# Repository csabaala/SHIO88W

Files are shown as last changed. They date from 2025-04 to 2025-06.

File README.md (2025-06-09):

# SHIO88W

ESP32 based DIN rail mount IO board.

More [Pictures](/Pictures#assembled-boards) and [Video](https://youtu.be/fpFCvI0ayuA) of the assembled board and extensions.

Example [ESPHome configs](/ESPHome)

## Features

* 12V DC input for powering
* 8 open collector output (50 mA load per channel)
* 8 opto isolated input
* LEDs for output and input status
* 1 sensor input (ds18b20, dht)
* 14 pin IDC connector for direct GPIO access

View [3D model](https://3dviewer.net/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)

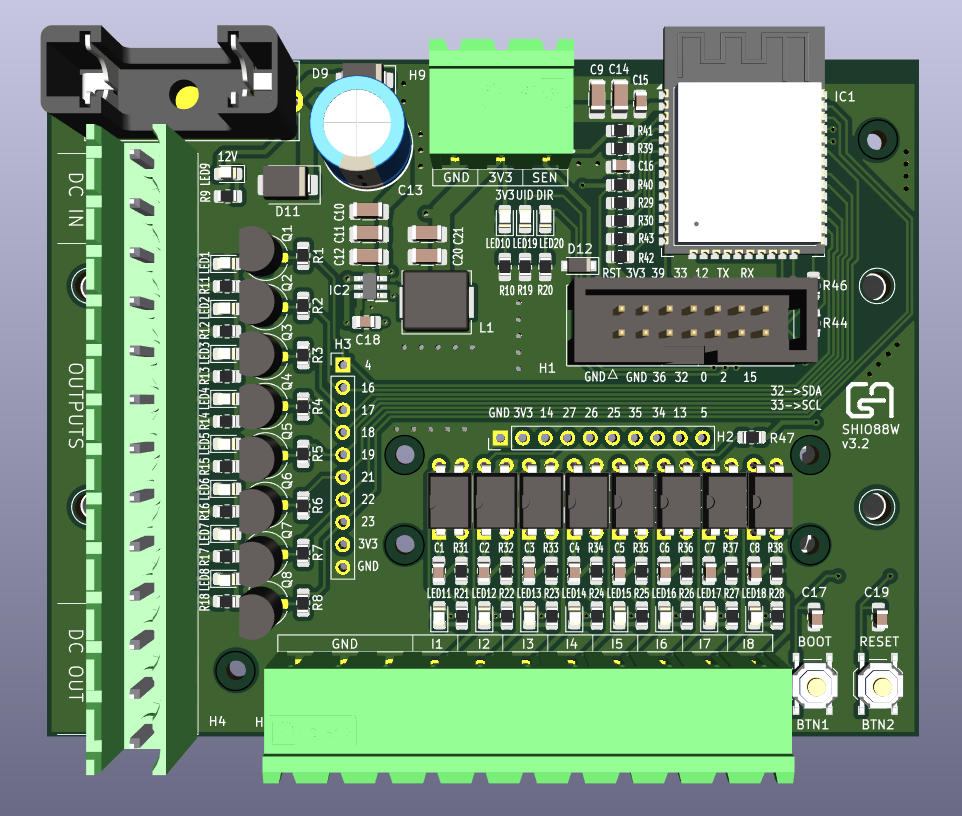
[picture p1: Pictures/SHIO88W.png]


## Extensions

### SHADRS485

Extension board mountable top of the SHIO88W board.

* Sockets and breakout for 2 ADS1115 AD converter
* On board voltage dividers for each channel
* RS-485 interface

View [3D model](https://3dviewer.net/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)

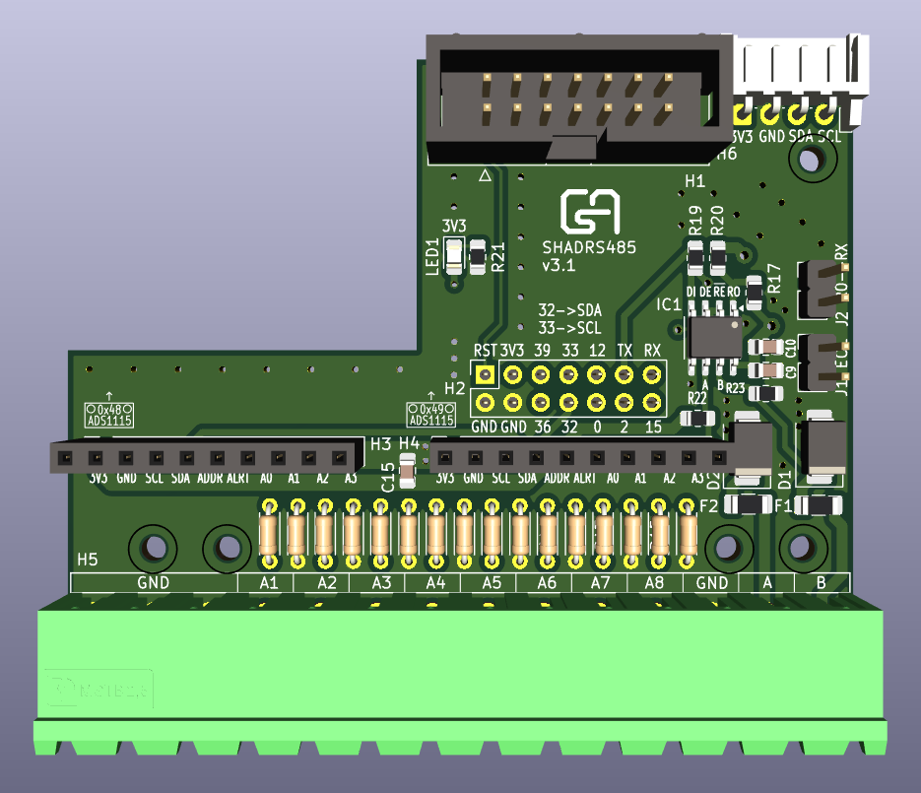
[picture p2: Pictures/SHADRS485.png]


### SHHMI

Control interface for SHIO88W.

* PCB for 128x64 OLED display and control buttons. Fits the 0.96 and 1.3 inch OLED versions.
* Mountable top of the SHADRS485 board

View [3D model](https://3dviewer.net/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)

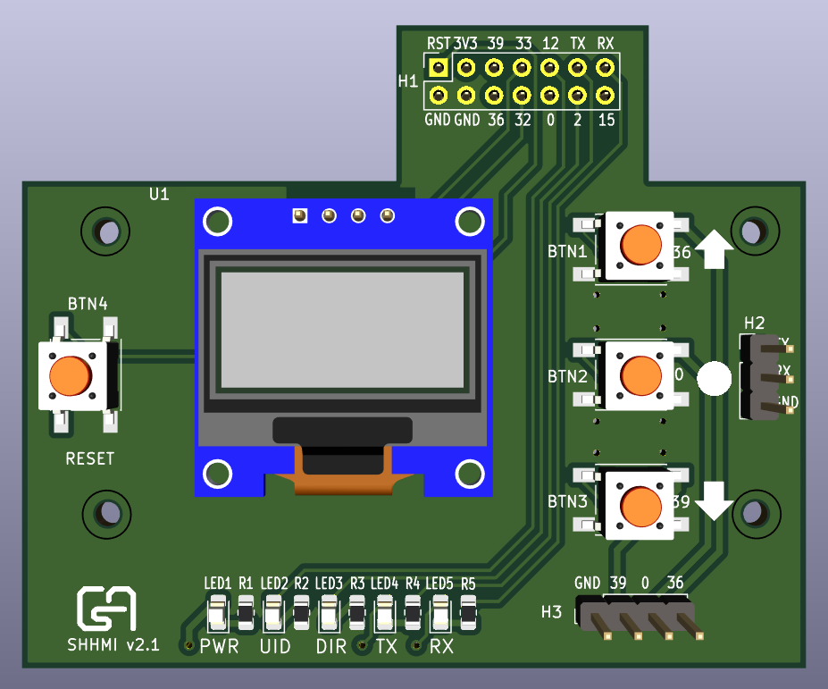
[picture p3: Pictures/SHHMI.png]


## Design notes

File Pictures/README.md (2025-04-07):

## Assembled boards

The SMD components sitting on the front side of the SHIO88W board manufactured by JLCPCB SMT assembly.

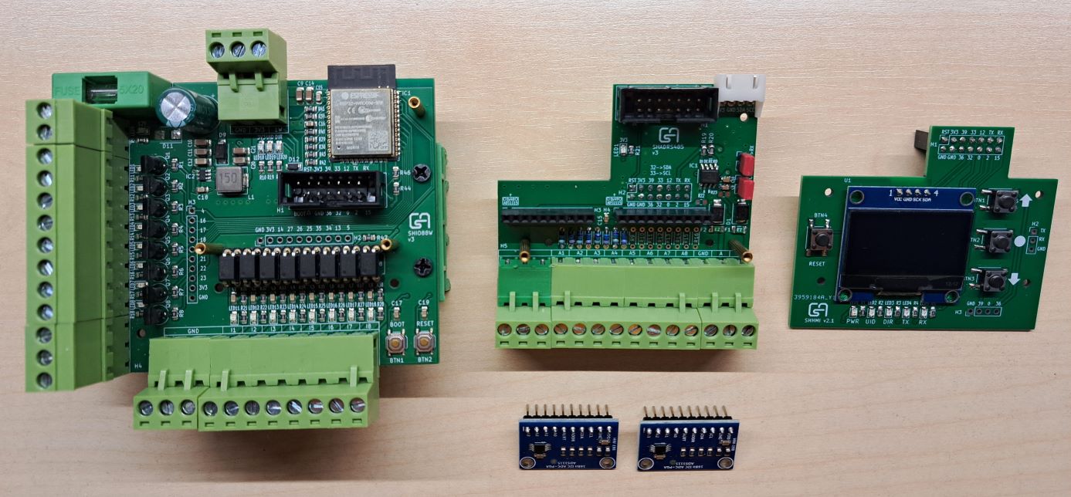
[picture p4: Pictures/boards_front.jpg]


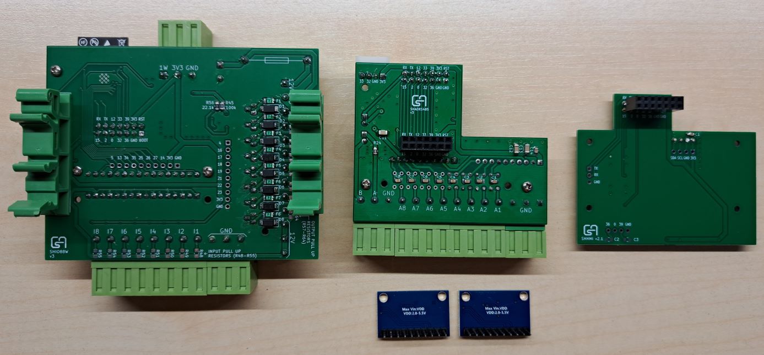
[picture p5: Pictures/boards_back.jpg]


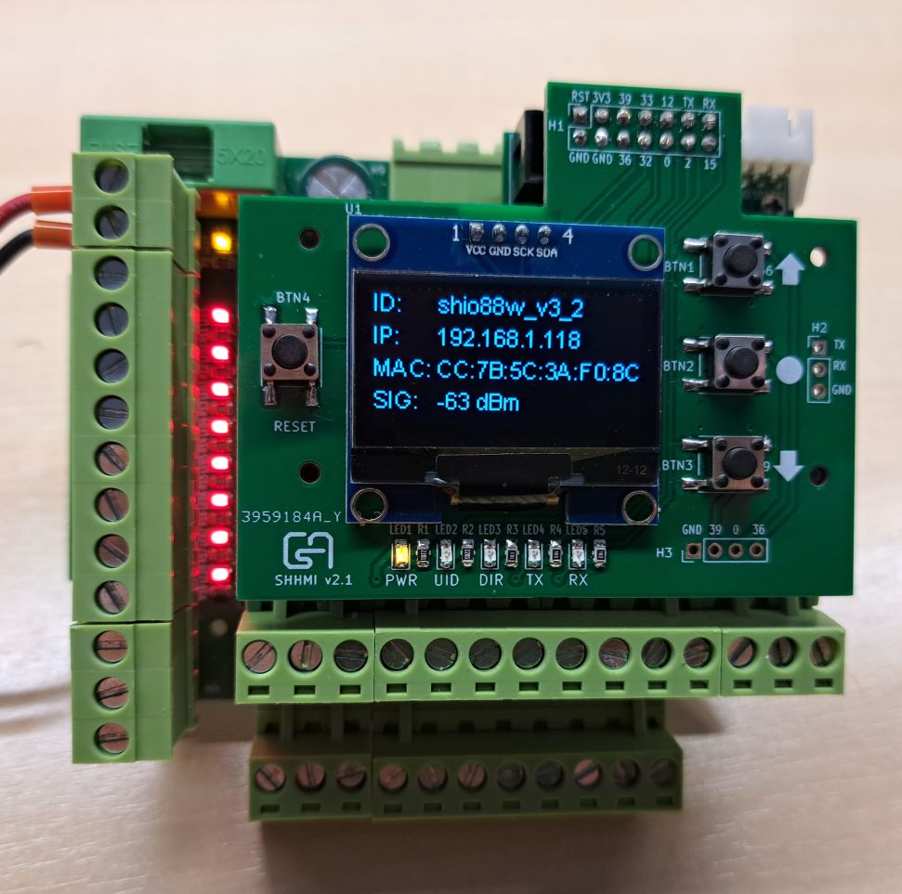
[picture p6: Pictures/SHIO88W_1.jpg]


Fits into home distribution boxes:

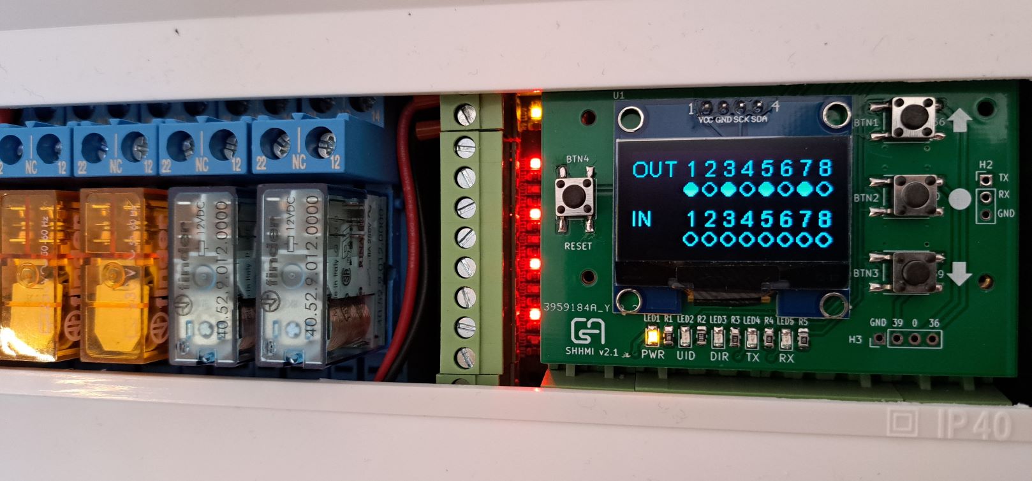
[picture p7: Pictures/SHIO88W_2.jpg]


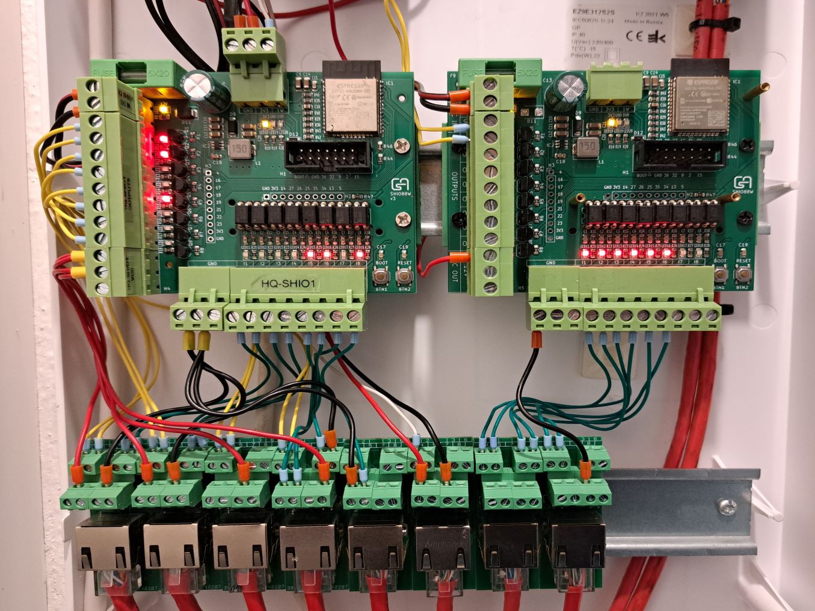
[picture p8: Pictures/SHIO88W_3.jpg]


## SHADRS485

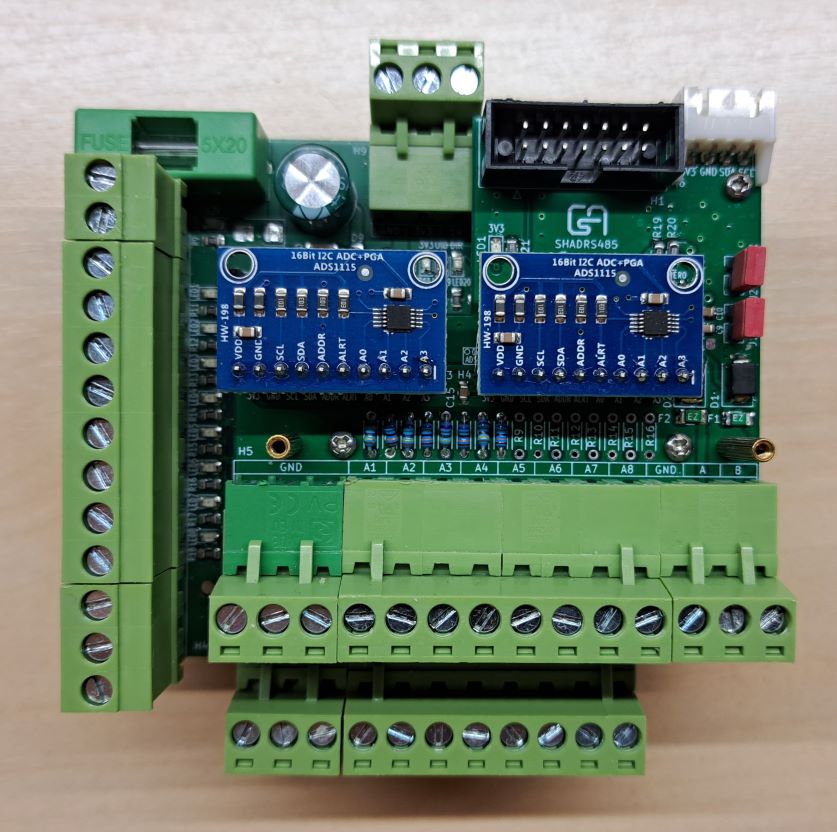
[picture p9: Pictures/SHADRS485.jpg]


## 3D images

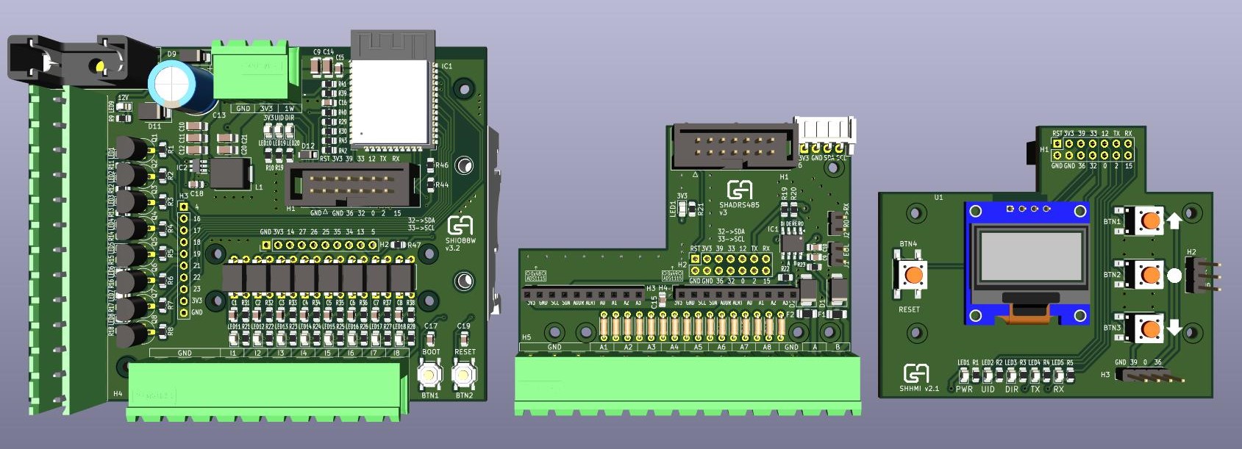
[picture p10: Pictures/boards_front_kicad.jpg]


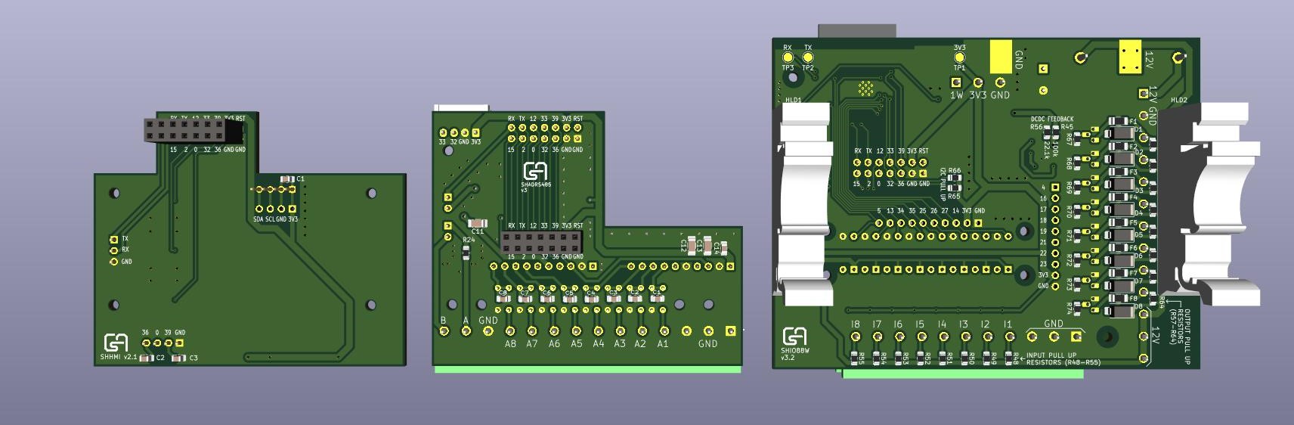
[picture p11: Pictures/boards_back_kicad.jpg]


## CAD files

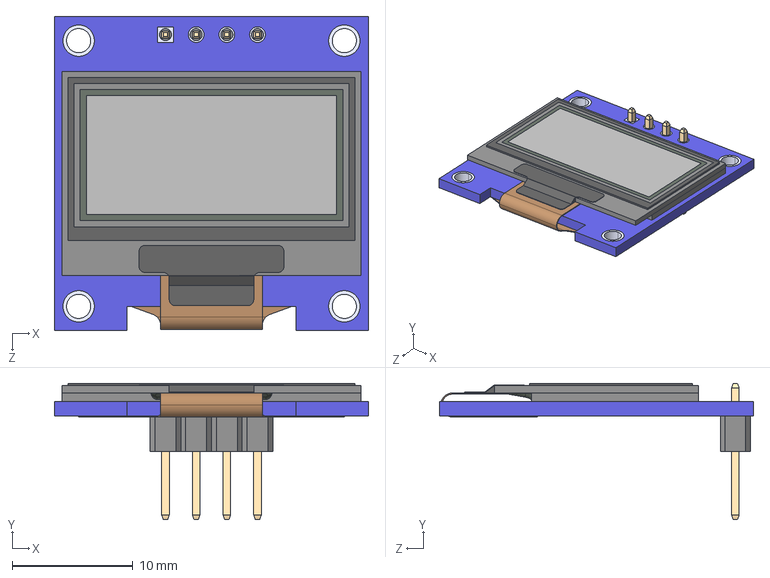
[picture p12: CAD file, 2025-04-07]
Hardware/SHHMI/extras/DM-OLED096-636.step
26.0 x 11.3 x 26.0 mm
DM-OLED096-636_Module
DM-OLED096-636_Panel

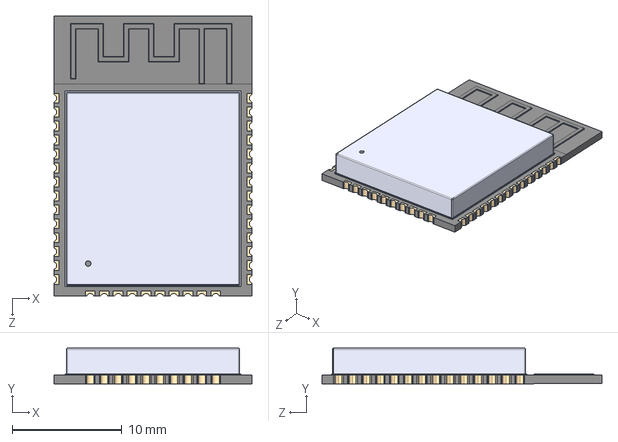
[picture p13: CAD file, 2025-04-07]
Hardware/SHIO88W/extras/ESP32-WROOM-32E.STEP
18.0 x 3.25 x 25.5 mm

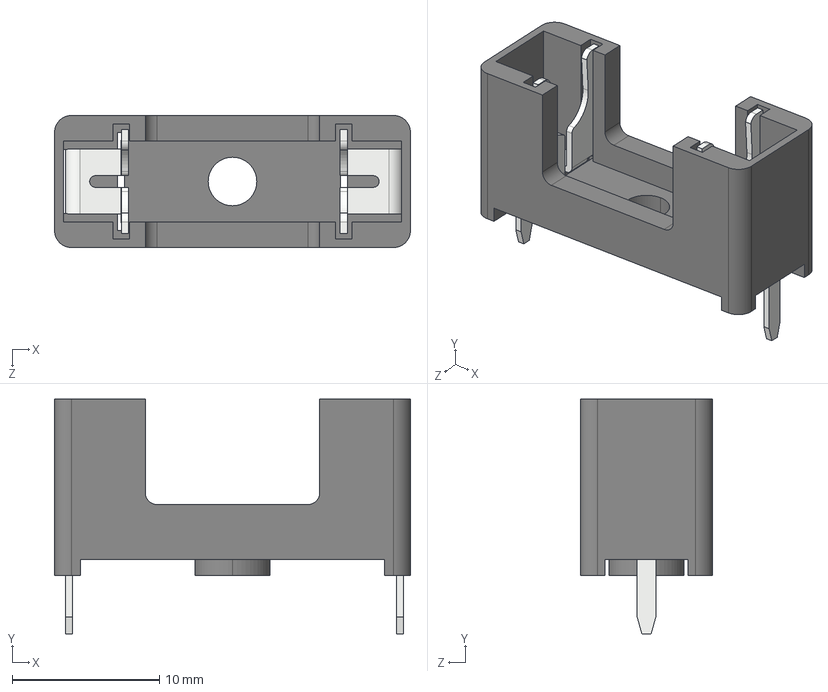
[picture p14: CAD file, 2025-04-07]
Hardware/SHIO88W/extras/fuse/4628.step
24.2 x 16.0 x 8.99 mm

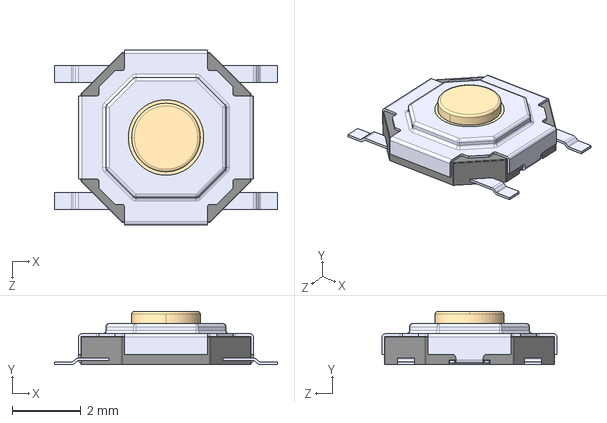
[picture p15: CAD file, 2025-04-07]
Hardware/SHIO88W/extras/TS-1187A-B-A-B.STEP
6.50 x 1.55 x 5.10 mm

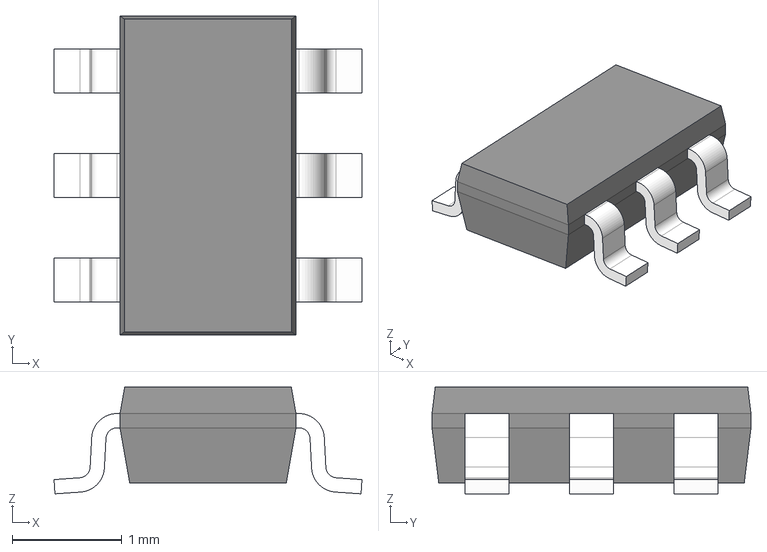
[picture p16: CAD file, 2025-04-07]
Hardware/SHIO88W/extras/LMR51420/LMR51420XDDCR.stp
2.80 x 2.90 x 0.97 mm
BODY-SOT
LEAD-SOT x 6

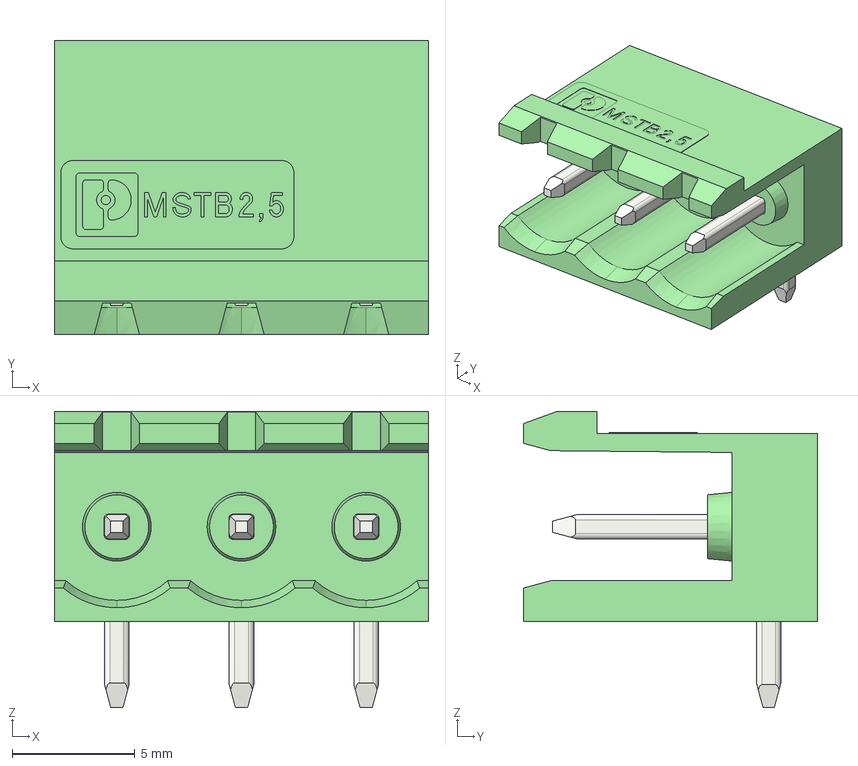
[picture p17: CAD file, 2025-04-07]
Hardware/SHIO88W/extras/MSTB 2,5 3-G-5,08/1759020.step
15.2 x 12.0 x 12.1 mm

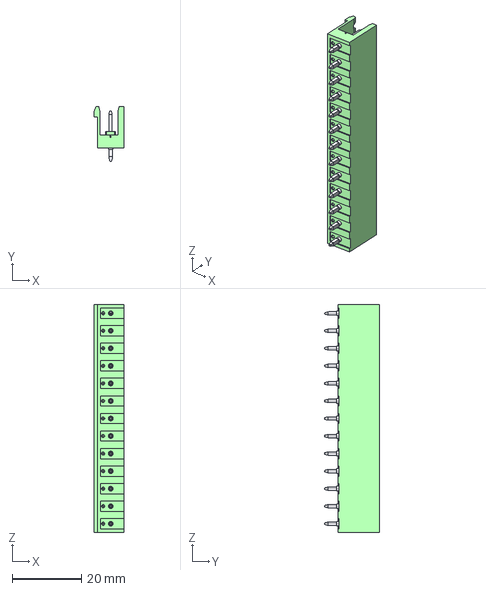
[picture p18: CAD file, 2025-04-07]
Hardware/SHIO88W/extras/MSTBV 2,513-G-5,08/1758128.stp
8.60 x 15.9 x 66.0 mm

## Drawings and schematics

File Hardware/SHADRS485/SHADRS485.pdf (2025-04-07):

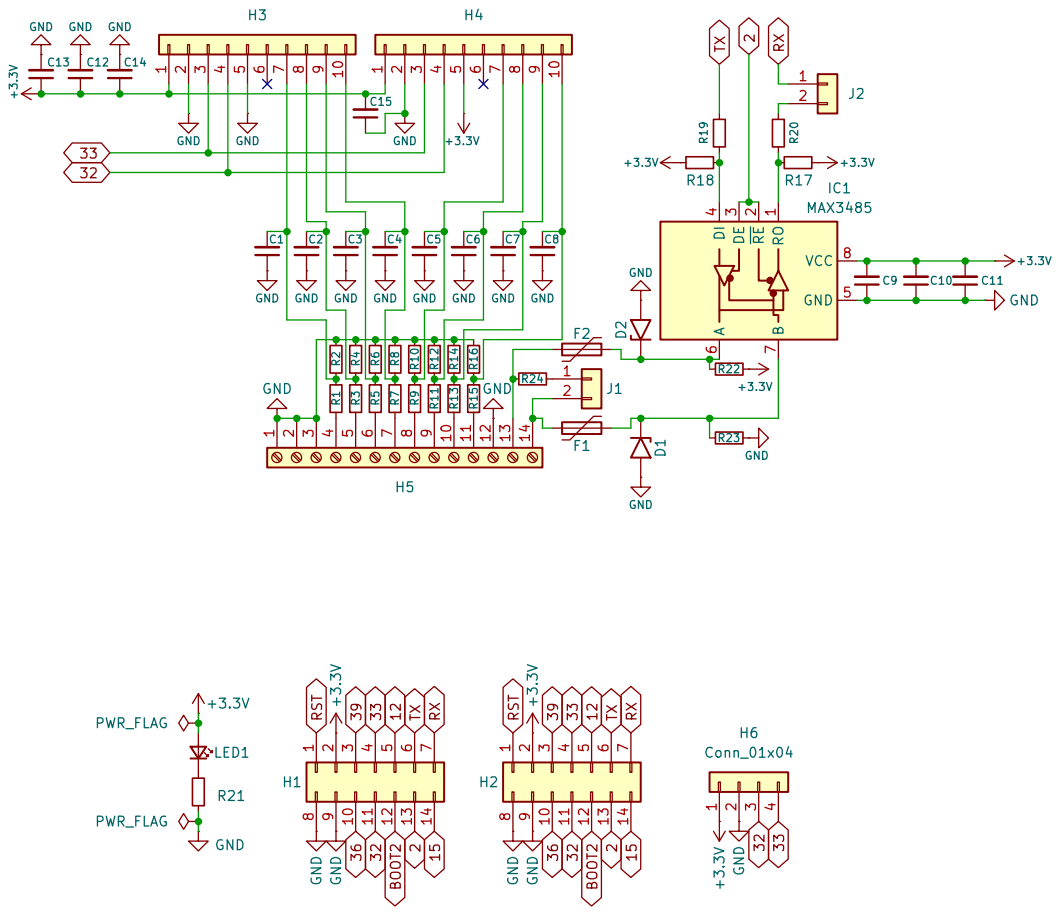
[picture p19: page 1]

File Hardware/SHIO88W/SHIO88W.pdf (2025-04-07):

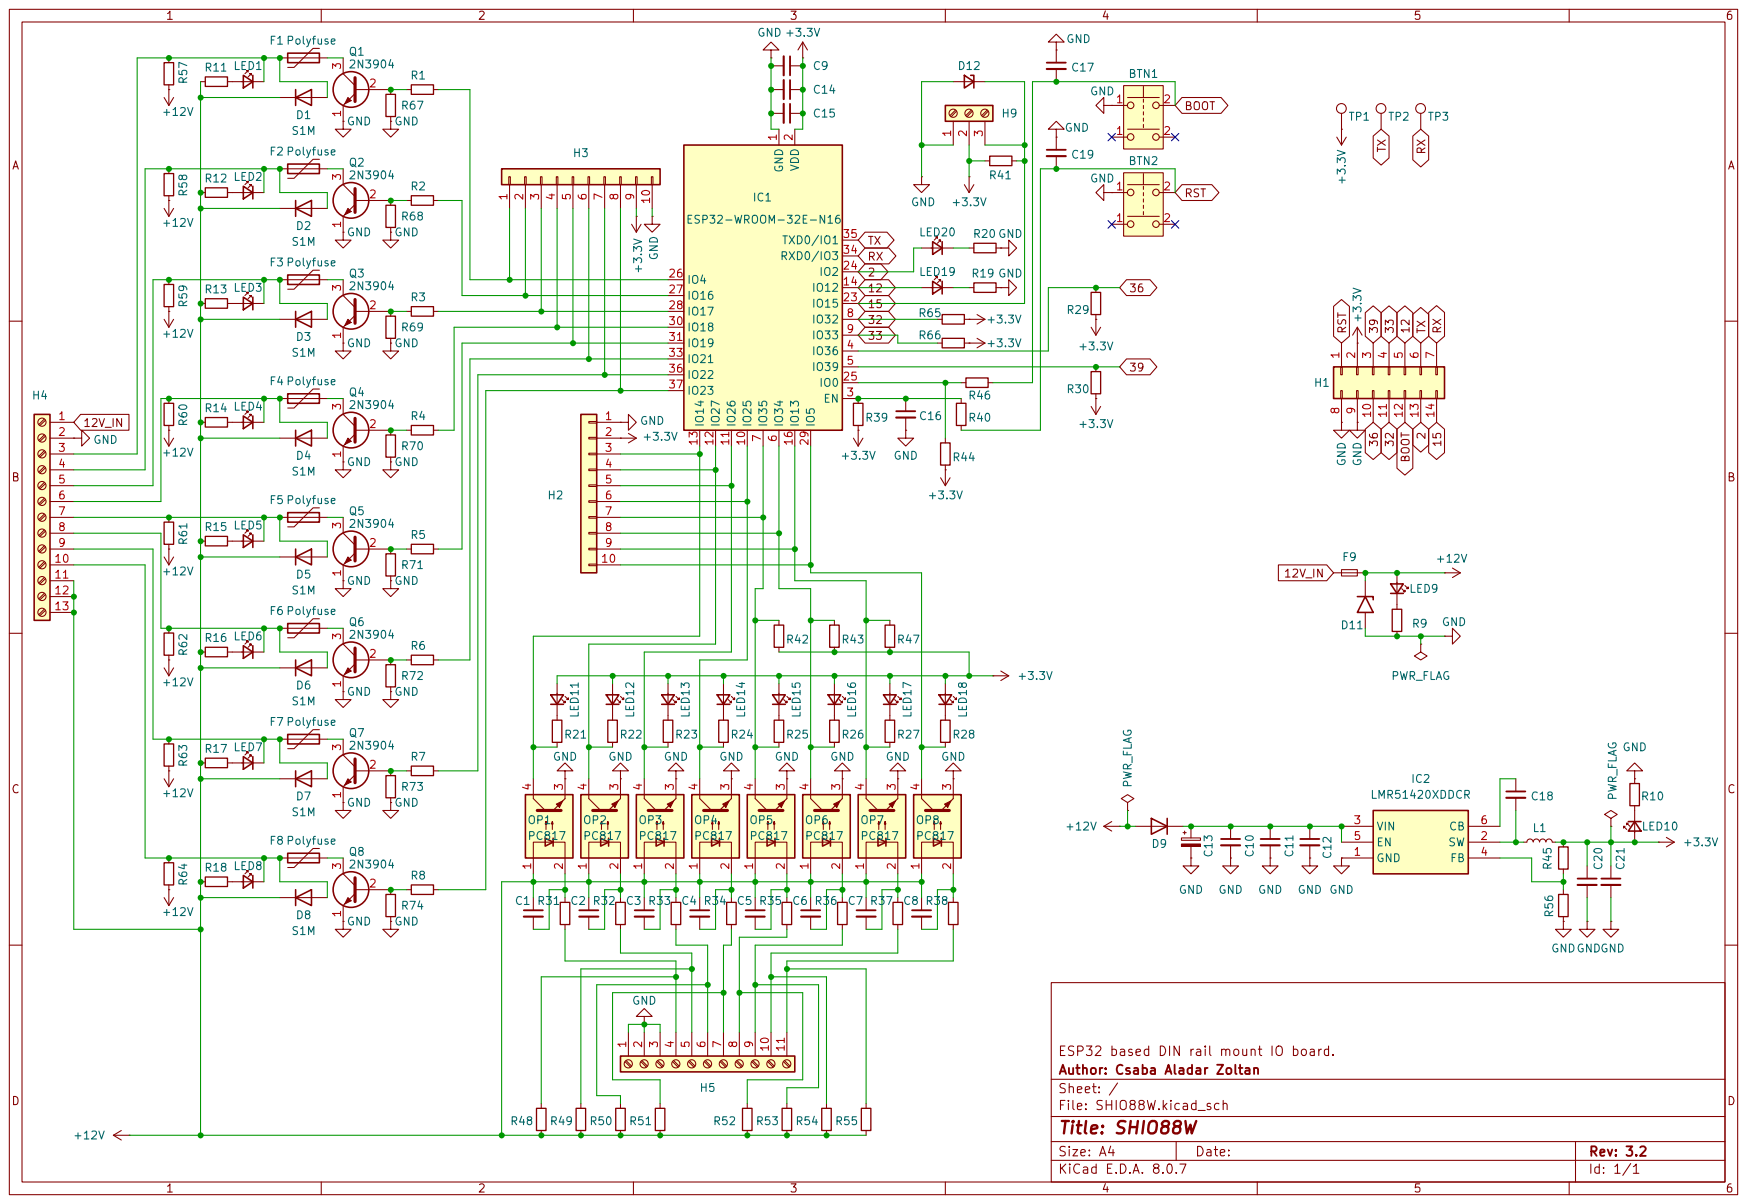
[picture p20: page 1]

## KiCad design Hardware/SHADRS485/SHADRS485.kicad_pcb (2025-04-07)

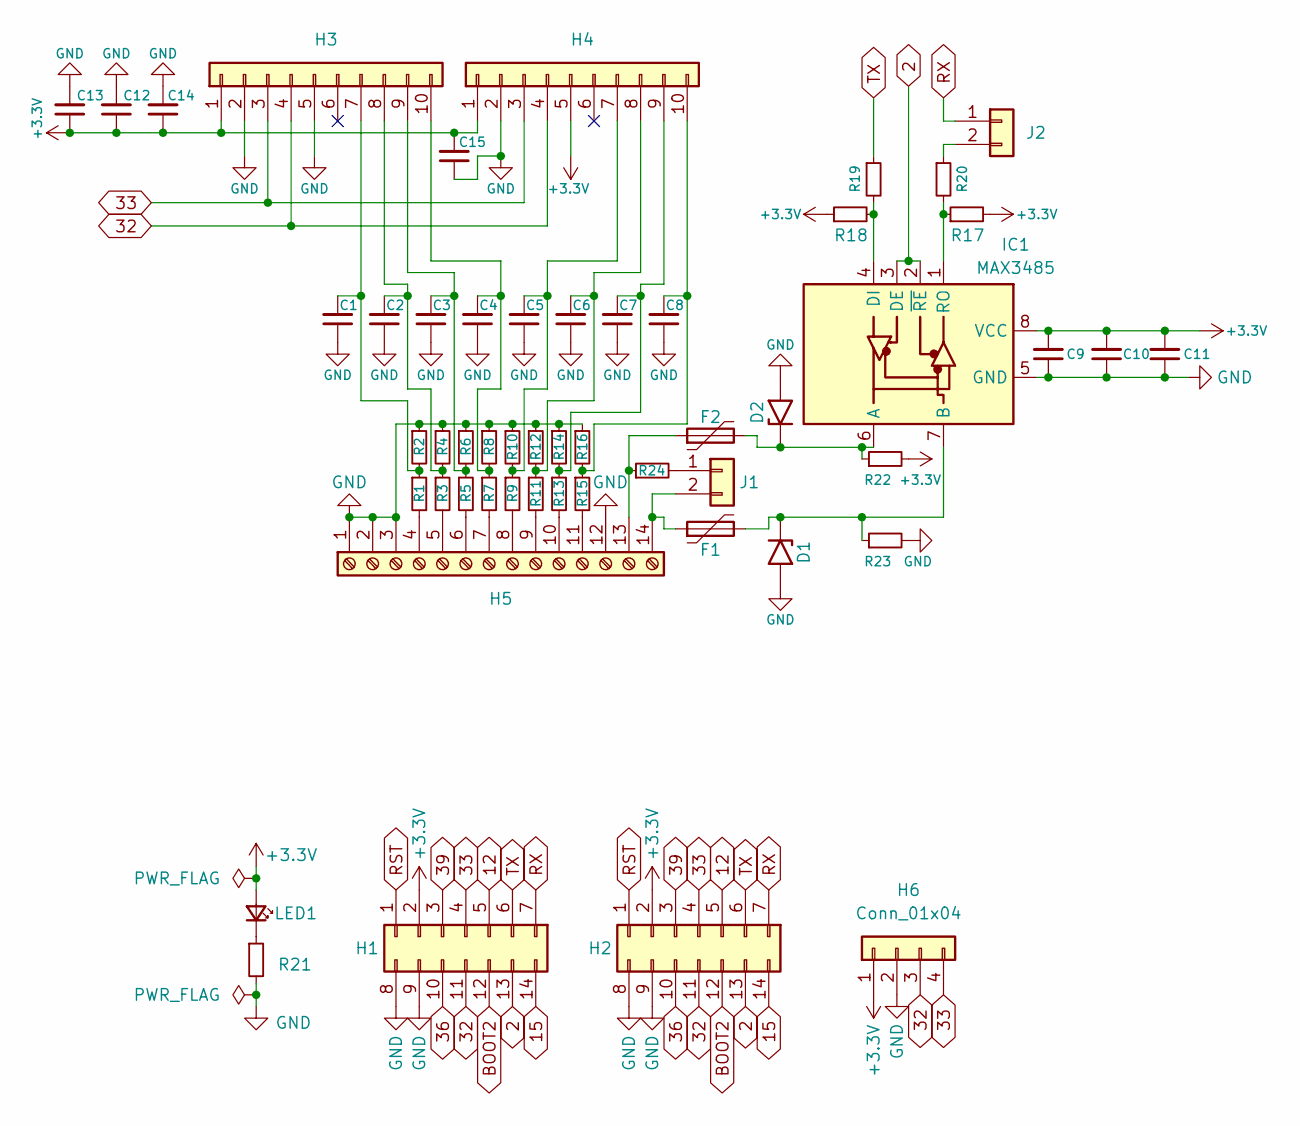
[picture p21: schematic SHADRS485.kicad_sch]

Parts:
C1, C2, C3, C4, C5, C6, C7, C8, C9, C10, C14, C15: C_Small; C_0805_2012Metric_Pad1.18x1.45mm_HandSolder; LCSC C49678
C11, C12, C13: C_Small; C_1206_3216Metric_Pad1.33x1.80mm_HandSolder; LCSC C50254
D1, D2: SMBJ12CA; D_SMB; LCSC C353397
F1, F2: Polyfuse; Fuse_1206_3216Metric_Pad1.42x1.75mm_HandSolder; LCSC C2830235
H1: Conn_02x07_Top_Bottom; IDC-Header_2x07_P2.54mm_Vertical
H2: Conn_02x07_Top_Bottom; PinSocket_2x07_P2.54mm_Vertical
H3, H4: Conn_01x10; PinSocket_1x10_P2.54mm_Vertical
H5: Screw_Terminal_01x14; MSTB 2,5 14-G-5,08
H6: Conn_01x04; JST_EH_S4B-EH_1x04_P2.50mm_Horizontal
IC1: MAX3485; SOIC-8_3.9x4.9mm_P1.27mm; LCSC C9943
J1, J2: Conn_01x02; PinHeader_1x02_P2.54mm_Vertical
LED1: LED_Small; LED_0805_2012Metric_Pad1.15x1.40mm_HandSolder; LCSC C2296
R1, R2, R3, R4, R5, R6, R7, R8, R9, R10, R11, R12, R13, R14, R15, R16: R_Small; R_Axial_DIN0204_L3.6mm_D1.6mm_P5.08mm_Horizontal
R17, R18, R21: R_Small; R_0805_2012Metric_Pad1.20x1.40mm_HandSolder; LCSC C17414
R19, R20: R_Small; R_0805_2012Metric_Pad1.20x1.40mm_HandSolder; LCSC C17408
R22, R23: R_Small; R_0805_2012Metric_Pad1.20x1.40mm_HandSolder
R24: R_Small; R_0805_2012Metric_Pad1.20x1.40mm_HandSolder; LCSC C17437

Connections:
2: H1.13, H2.13, IC1.2 (~RE), IC1.3 (DE)
12: H1.5, H2.5
15: H1.14, H2.14
32: H1.11, H2.11, H3.4, H4.4, H6.3
33: H1.4, H2.4, H3.3, H4.3, H6.4
36: H1.10, H2.10
39: H1.3, H2.3
+3.3V: C9.2, C10.2, C11.2, C12.1, C13.1, C14.1, C15.2, H1.2, H2.2, H3.1, H4.1, H4.5, H6.1, IC1.8 (VCC), LED1.2 (A), R17.2, R18.1, R22.2
BOOT2: H1.12, H2.12
GND: C1.1, C2.1, C3.1, C4.1, C5.1, C6.1, C7.1, C8.1, C9.1, C10.1, C11.1, C12.2, C13.2, C14.2, C15.1, D1.2 (A2), D2.2 (A2), H1.8, H1.9, H2.8, H2.9, H3.2, H3.5, H4.2, H5.1, H5.2, H5.3, H5.12, H6.2, IC1.5 (GND), R2.1, R4.1, R6.1, R8.1, R10.1, R12.1, R14.1, R16.1, R21.2, R23.2
unnamed: D1.1 (A1), F1.2, IC1.7 (B), R23.1
unnamed: D2.1 (A1), F2.2, IC1.6 (A), R22.1
unnamed: C1.2, H3.7, R1.1, R2.2
unnamed: C2.2, H3.8, R3.1, R4.2
unnamed: C3.2, H3.9, R5.1, R6.2
unnamed: C4.2, H3.10, R7.1, R8.2
unnamed: C5.2, H4.7, R9.1, R10.2
unnamed: C6.2, H4.8, R11.1, R12.2
unnamed: C7.2, H4.9, R13.1, R14.2
unnamed: C8.2, H4.10, R15.1, R16.2
unnamed: H5.4, R1.2
unnamed: H5.5, R3.2
unnamed: H5.6, R5.2
unnamed: H5.7, R7.2
unnamed: H5.8, R9.2
unnamed: H5.9, R11.2
unnamed: H5.10, R13.2
unnamed: H5.11, R15.2
unnamed: F2.1, H5.13, R24.1
unnamed: F1.1, H5.14, J1.2
unnamed: IC1.4 (DI), R18.2, R19.2
unnamed: IC1.1 (RO), R17.1, R20.2
unnamed: J1.1, R24.2
unnamed: J2.2, R20.1
unnamed: LED1.1 (K), R21.1
RST: H1.1, H2.1
RX: H1.7, H2.7, J2.1
TX: H1.6, H2.6, R19.1

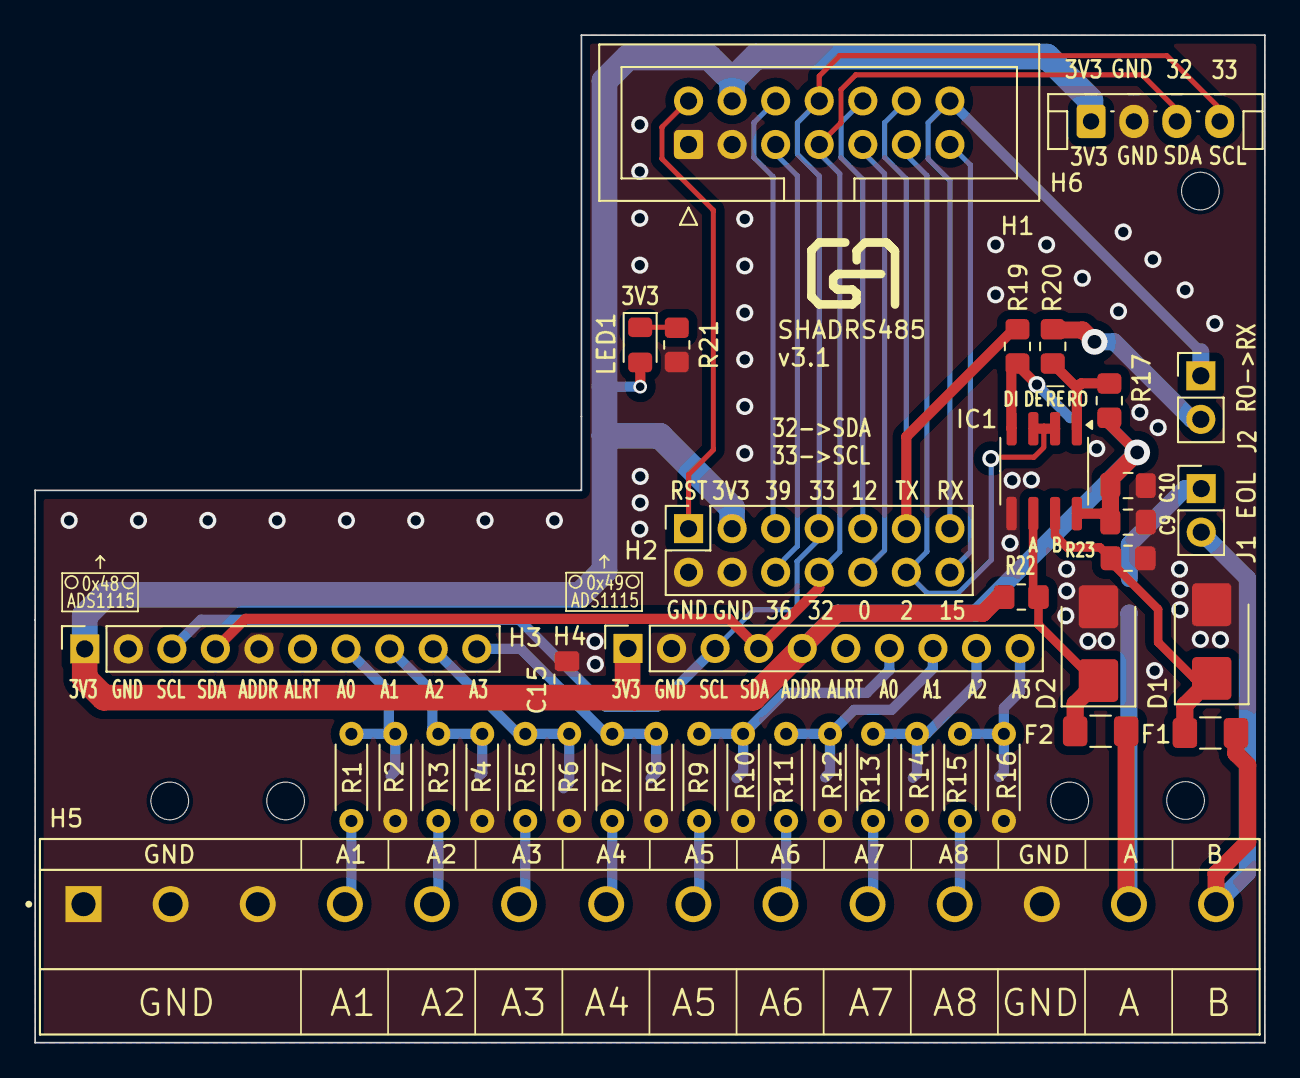
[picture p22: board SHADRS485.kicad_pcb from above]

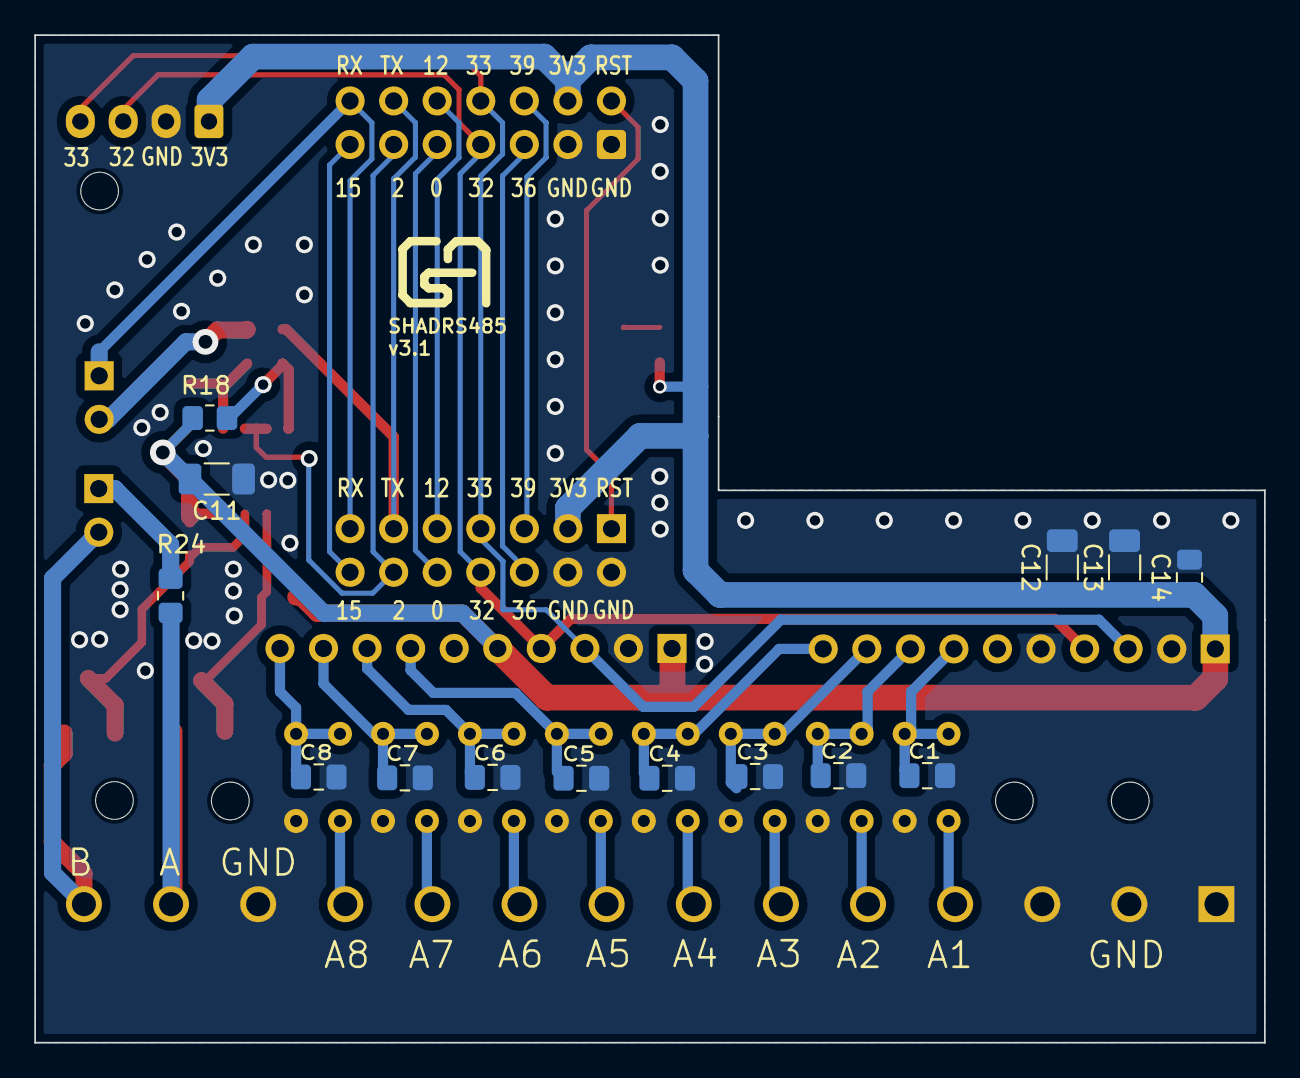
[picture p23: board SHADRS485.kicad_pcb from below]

Board: 2 copper layers, 71.7 x 58.8 mm, 53 parts (14 on the bottom side), 38 nets.

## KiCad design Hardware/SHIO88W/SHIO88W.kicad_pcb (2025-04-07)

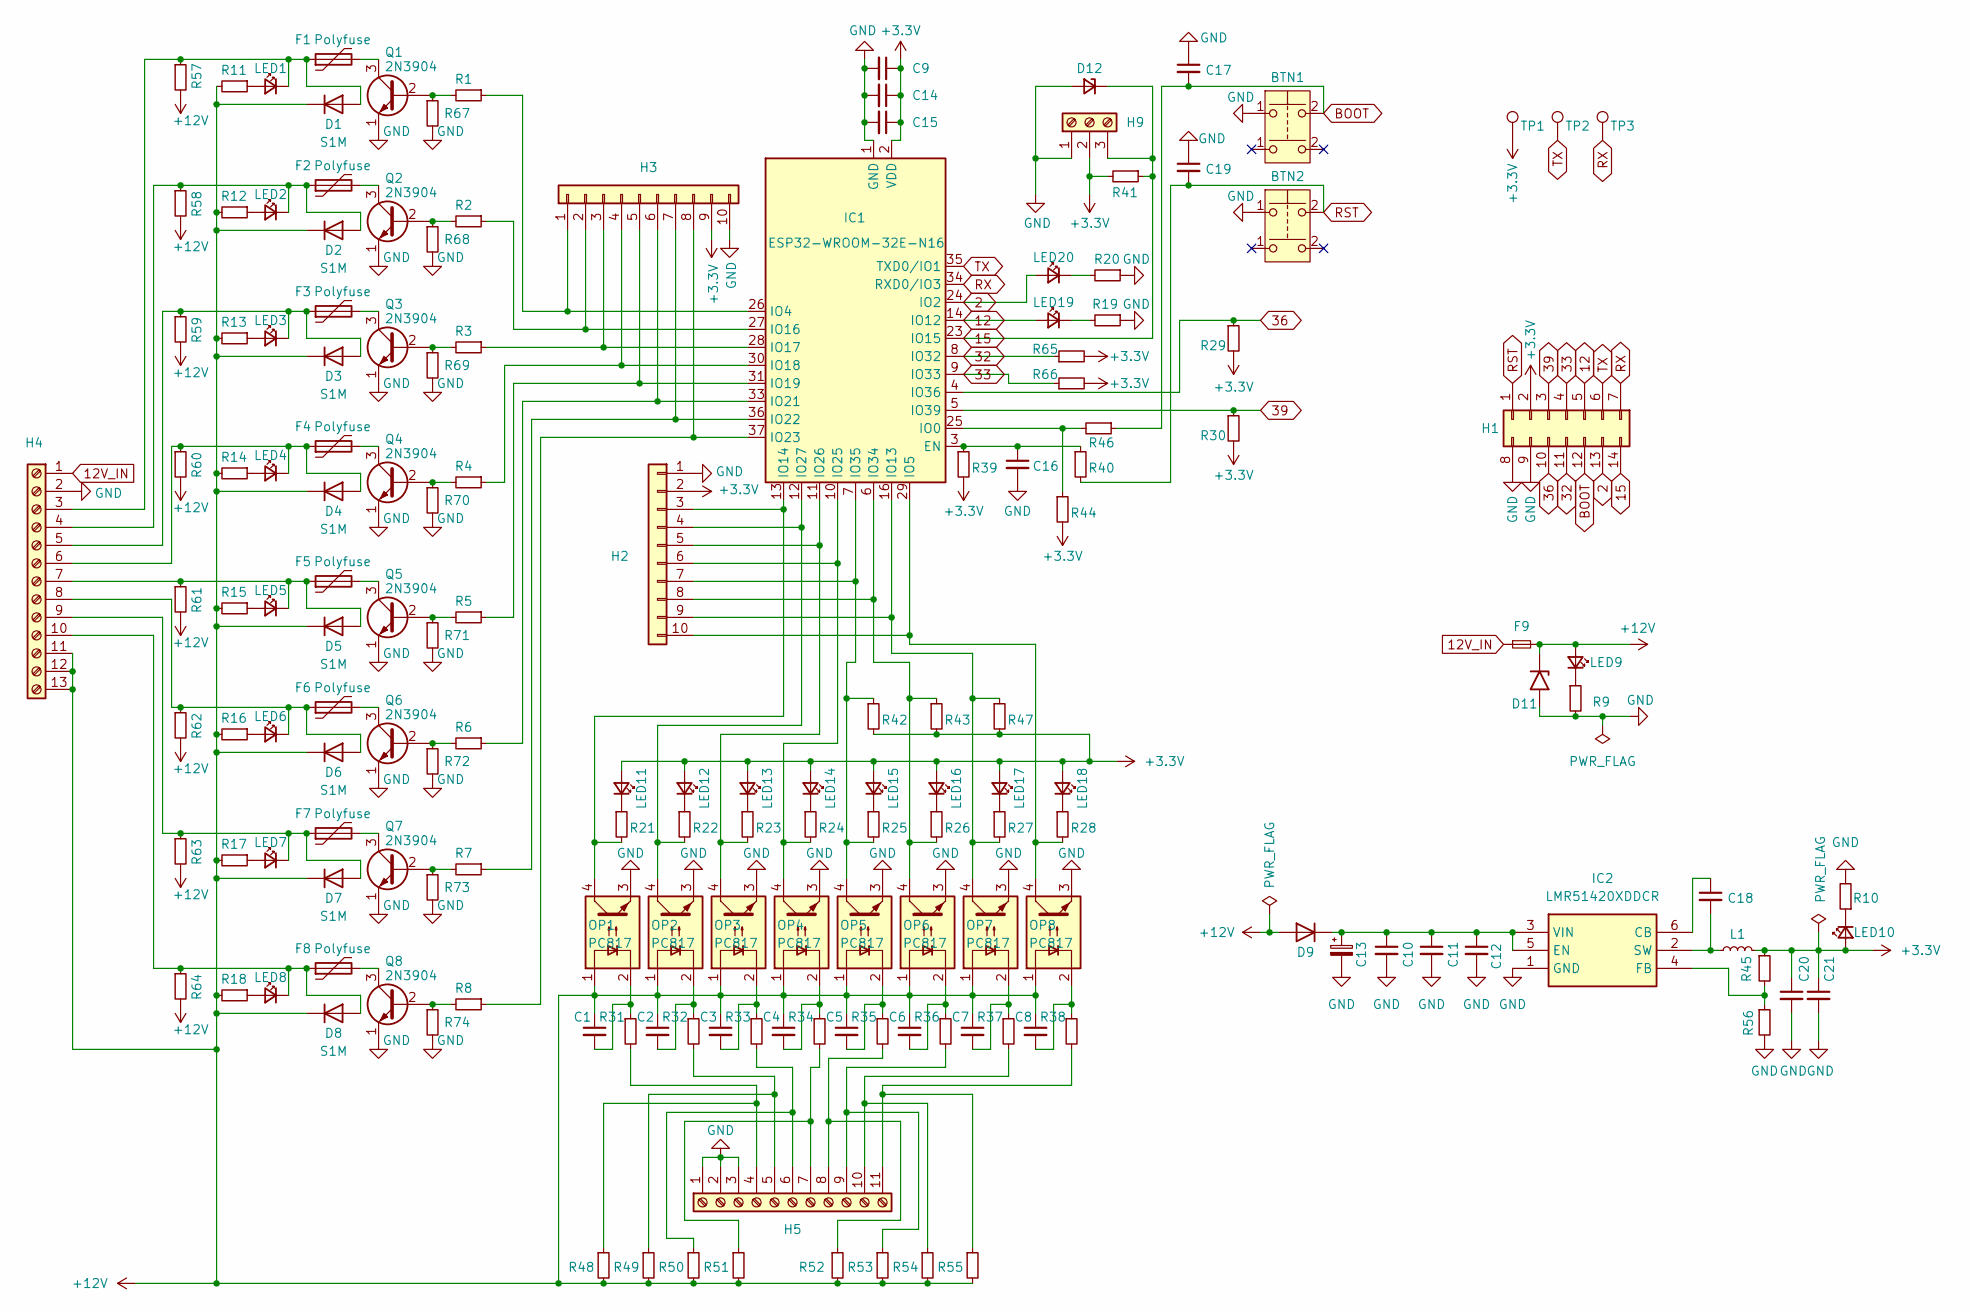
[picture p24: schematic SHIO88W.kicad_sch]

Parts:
BTN1, BTN2: SW_Push_Dual; SW_Push_1P1T_XKB_TS-1187A; LCSC C318884
C1, C2, C3, C4, C5, C6, C7, C8: C_Small; C_0805_2012Metric_Pad1.18x1.45mm_HandSolder; LCSC C1710
C9, C14, C20, C21: C_Small; C_1206_3216Metric_Pad1.33x1.80mm_HandSolder; LCSC C12891
C10, C11: C_Small; C_1206_3216Metric_Pad1.33x1.80mm_HandSolder; LCSC C13585
C12: C_Small; C_1206_3216Metric_Pad1.33x1.80mm_HandSolder; LCSC C50254
C13: C_Polarized_Small; CP_Radial_D10.0mm_P5.00mm
C15, C17, C18, C19: C_Small; C_0805_2012Metric_Pad1.18x1.45mm_HandSolder; LCSC C49678
C16: C_Small; C_0805_2012Metric_Pad1.18x1.45mm_HandSolder; LCSC C28323
D1, D2, D3, D4, D5, D6, D7, D8: S1M; D_SMA
D9: S1M; D_SMA; LCSC C412437
D11: SM6T18A; D_SMB; LCSC C353369
D12: D_Zener_Small; Nexperia_CFP3_SOD-123W; LCSC C2903912
F1, F2, F3, F4, F5, F6, F7, F8: Polyfuse; Fuse_1206_3216Metric_Pad1.42x1.75mm_HandSolder
F9: Fuse_Small; FUSE_holder
H1: Conn_02x07_Top_Bottom; IDC-Header_2x07_P2.54mm_Vertical
H2, H3: Conn_01x10; PinHeader_1x10_P2.54mm_Vertical
H4: Screw_Terminal_01x13; TerminalBlock_MSTBV 2,513-G-5,08
H5: Screw_Terminal_01x11; TerminalBlock_MSTB 2,511-G-5,08
H9: Screw_Terminal_01x03; TerminalBlock_MSTB 2,5 3-G-5,08
IC1: ESP32-WROOM-32E-N16; ESP32-WROOM-32E; JLCPCB Rotation Offset 270
IC2: LMR51420XDDCR; LMR51420; Mouser Part Number 595-LMR51420XDDCR
L1: L_Small; L_Chilisin_BMRx00060630; LCSC C497872
LED1, LED2, LED3, LED4, LED5, LED6, LED7, LED8, LED11, LED12, LED13, LED14, LED15, LED16, LED17, LED18, LED19: LED_Small; LED_0805_2012Metric_Pad1.15x1.40mm_HandSolder; LCSC C84256
LED9, LED10: LED_Small; LED_0805_2012Metric_Pad1.15x1.40mm_HandSolder; LCSC C2296
LED20: LED_Small; LED_0805_2012Metric_Pad1.15x1.40mm_HandSolder; LCSC C2297
OP1, OP2, OP3, OP4, OP5, OP6, OP7, OP8: PC817; PC817_custom
Q1, Q2, Q3, Q4, Q5, Q6, Q7, Q8: 2N3904; TO-92_HandSolder
R1, R2, R3, R4, R5, R6, R7, R8: R_Small; R_0805_2012Metric_Pad1.20x1.40mm_HandSolder; LCSC C17513
R9, R11, R12, R13, R14, R15, R16, R17, R18, R20, R29, R30, R39, R42, R43, R44, R47: R_Small; R_0805_2012Metric_Pad1.20x1.40mm_HandSolder; LCSC C17414
R10, R19, R21, R22, R23, R24, R25, R26, R27, R28, R31, R32, R33, R34, R35, R36, R37, R38: R_Small; R_0805_2012Metric_Pad1.20x1.40mm_HandSolder; LCSC C17520
R40, R46: R_Small; R_0805_2012Metric_Pad1.20x1.40mm_HandSolder; LCSC C17710
R41: R_Small; R_0805_2012Metric_Pad1.20x1.40mm_HandSolder; LCSC C17673
R45, R48, R49, R50, R51, R52, R53, R54, R55, R56, R57, R58, R59, R60, R61, R62, R63, R64, R65, R66, R67, R68, R69, R70, R71, R72, R73, R74: R_Small; R_0805_2012Metric_Pad1.20x1.40mm_HandSolder
TP1, TP2, TP3: TestPoint; TestPoint_Pad_D2.0mm_custom

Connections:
2: H1.13, IC1.24 (IO2), LED20.2 (A)
12: H1.5, IC1.14 (IO12), LED19.2 (A)
12V_IN: F9.1, H4.1
15: D12.1 (K), H1.14, H9.3, IC1.23 (IO15), R41.1
32: H1.11, IC1.8 (IO32), R65.1
33: H1.4, IC1.9 (IO33), R66.1
36: H1.10, IC1.4 (IO36), R29.1
39: H1.3, IC1.5 (IO39), R30.1
+3.3V: C9.1, C14.1, C15.1, C20.1, C21.1, H1.2, H2.2, H3.9, H9.2, IC1.2 (VDD), L1.2, LED10.2 (A), LED11.2 (A), LED12.2 (A), LED13.2 (A), LED14.2 (A), LED15.2 (A), LED16.2 (A), LED17.2 (A), LED18.2 (A), R29.2, R30.2, R39.2, R41.2, R42.2, R43.2, R44.2, R45.1, R47.2, R65.2, R66.2, TP1.1
+12V: C1.1, C2.1, C3.1, C4.1, C5.1, C6.1, C7.1, C8.1, D1.1 (K), D2.1 (K), D3.1 (K), D4.1 (K), D5.1 (K), D6.1 (K), D7.1 (K), D8.1 (K), D9.2 (A), D11.1 (A1), F9.2, H4.11, H4.12, H4.13, LED9.2 (A), OP1.1, OP2.1, OP3.1, OP4.1, OP5.1, OP6.1, OP7.1, OP8.1, R11.2, R12.2, R13.2, R14.2, R15.2, R16.2, R17.2, R18.2, R48.2, R49.2, R50.2, R51.2, R52.2, R53.2, R54.2, R55.2, R57.2, R58.2, R59.2, R60.2, R61.2, R62.2, R63.2, R64.2
BOOT: BTN1.2, C17.2, H1.12, R46.1
GND: BTN1.1, BTN2.1, C9.2, C10.2, C11.2, C12.2, C13.2, C14.2, C15.2, C16.2, C17.1, C19.1, C20.2, C21.2, D11.2 (A2), D12.2 (A), H1.8, H1.9, H2.1, H3.10, H4.2, H5.1, H5.2, H5.3, H9.1, IC1.1 (GND), IC1.15 (GND), IC1.38 (GND), IC1.39 (GND), IC2.1 (GND), OP1.3, OP2.3, OP3.3, OP4.3, OP5.3, OP6.3, OP7.3, OP8.3, Q1.1 (E), Q2.1 (E), Q3.1 (E), Q4.1 (E), Q5.1 (E), Q6.1 (E), Q7.1 (E), Q8.1 (E), R9.2, R10.2, R19.1, R20.1, R56.2, R67.2, R68.2, R69.2, R70.2, R71.2, R72.2, R73.2, R74.2
unnamed: C1.2, OP1.2, R31.1
unnamed: C2.2, OP2.2, R32.1
unnamed: C3.2, OP3.2, R33.1
unnamed: C4.2, OP4.2, R34.1
unnamed: C5.2, OP5.2, R35.1
unnamed: C6.2, OP6.2, R36.1
unnamed: C7.2, OP7.2, R37.1
unnamed: C8.2, OP8.2, R38.1
unnamed: D1.2 (A), F1.1, H4.3, LED1.1 (K), R57.1
unnamed: D2.2 (A), F2.1, H4.4, LED2.1 (K), R58.1
unnamed: D3.2 (A), F3.1, H4.5, LED3.1 (K), R59.1
unnamed: D4.2 (A), F4.1, H4.6, LED4.1 (K), R60.1
unnamed: D5.2 (A), F5.1, H4.7, LED5.1 (K), R61.1
unnamed: D6.2 (A), F6.1, H4.8, LED6.1 (K), R62.1
unnamed: D7.2 (A), F7.1, H4.9, LED7.1 (K), R63.1
unnamed: D8.2 (A), F8.1, H4.10, LED8.1 (K), R64.1
unnamed: C10.1, C11.1, C12.1, C13.1, D9.1 (K), IC2.3 (VIN), IC2.5 (EN)
unnamed: H2.3, IC1.13 (IO14), OP1.4, R21.2
unnamed: H2.4, IC1.12 (IO27), OP2.4, R22.2
unnamed: H2.5, IC1.11 (IO26), OP3.4, R23.2
unnamed: H2.6, IC1.10 (IO25), OP4.4, R24.2
unnamed: H2.7, IC1.7 (IO35), OP5.4, R25.2, R42.1
unnamed: H2.8, IC1.6 (IO34), OP6.4, R26.2, R43.1
unnamed: H2.9, IC1.16 (IO13), OP7.4, R27.2, R47.1
unnamed: H2.10, IC1.29 (IO5), OP8.4, R28.2
unnamed: H3.1, IC1.26 (IO4), R1.1
unnamed: H3.2, IC1.27 (IO16), R2.1
unnamed: H3.3, IC1.28 (IO17), R3.1
unnamed: H3.4, IC1.30 (IO18), R4.1
unnamed: H3.5, IC1.31 (IO19), R5.1
unnamed: H3.6, IC1.33 (IO21), R6.1
unnamed: H3.7, IC1.36 (IO22), R7.1
unnamed: H3.8, IC1.37 (IO23), R8.1
unnamed: H5.4, R31.2, R48.1
unnamed: H5.5, R32.2, R49.1
unnamed: H5.6, R33.2, R50.1
unnamed: H5.7, R34.2, R51.1
unnamed: H5.8, R35.2, R52.1
unnamed: H5.9, R36.2, R53.1
unnamed: H5.10, R37.2, R54.1
unnamed: H5.11, R38.2, R55.1
unnamed: C16.1, IC1.3 (EN), R39.1, R40.1
unnamed: IC1.25 (IO0), R44.1, R46.2
unnamed: C18.1, IC2.6 (CB)
unnamed: IC2.4 (FB), R45.2, R56.1
unnamed: C18.2, IC2.2 (SW), L1.1
unnamed: LED1.2 (A), R11.1
unnamed: LED2.2 (A), R12.1
unnamed: LED3.2 (A), R13.1
unnamed: LED4.2 (A), R14.1
unnamed: LED5.2 (A), R15.1
unnamed: LED6.2 (A), R16.1
unnamed: LED7.2 (A), R17.1
unnamed: LED8.2 (A), R18.1
unnamed: LED9.1 (K), R9.1
unnamed: LED10.1 (K), R10.1
unnamed: LED11.1 (K), R21.1
unnamed: LED12.1 (K), R22.1
unnamed: LED13.1 (K), R23.1
unnamed: LED14.1 (K), R24.1
unnamed: LED15.1 (K), R25.1
unnamed: LED16.1 (K), R26.1
unnamed: LED17.1 (K), R27.1
unnamed: LED18.1 (K), R28.1
unnamed: LED19.1 (K), R19.2
unnamed: LED20.1 (K), R20.2
unnamed: Q1.2 (B), R1.2, R67.1
unnamed: F1.2, Q1.3 (C)
unnamed: Q2.2 (B), R2.2, R68.1
unnamed: F2.2, Q2.3 (C)
unnamed: Q3.2 (B), R3.2, R69.1
unnamed: F3.2, Q3.3 (C)
unnamed: Q4.2 (B), R4.2, R70.1
unnamed: F4.2, Q4.3 (C)
unnamed: Q5.2 (B), R5.2, R71.1
unnamed: F5.2, Q5.3 (C)
unnamed: Q6.2 (B), R6.2, R72.1
unnamed: F6.2, Q6.3 (C)
unnamed: Q7.2 (B), R7.2, R73.1
unnamed: F7.2, Q7.3 (C)
unnamed: Q8.2 (B), R8.2, R74.1
unnamed: F8.2, Q8.3 (C)
RST: BTN2.2, C19.2, H1.1, R40.2
RX: H1.7, IC1.34 (RXD0/IO3), TP3.1
TX: H1.6, IC1.35 (TXD0/IO1), TP2.1

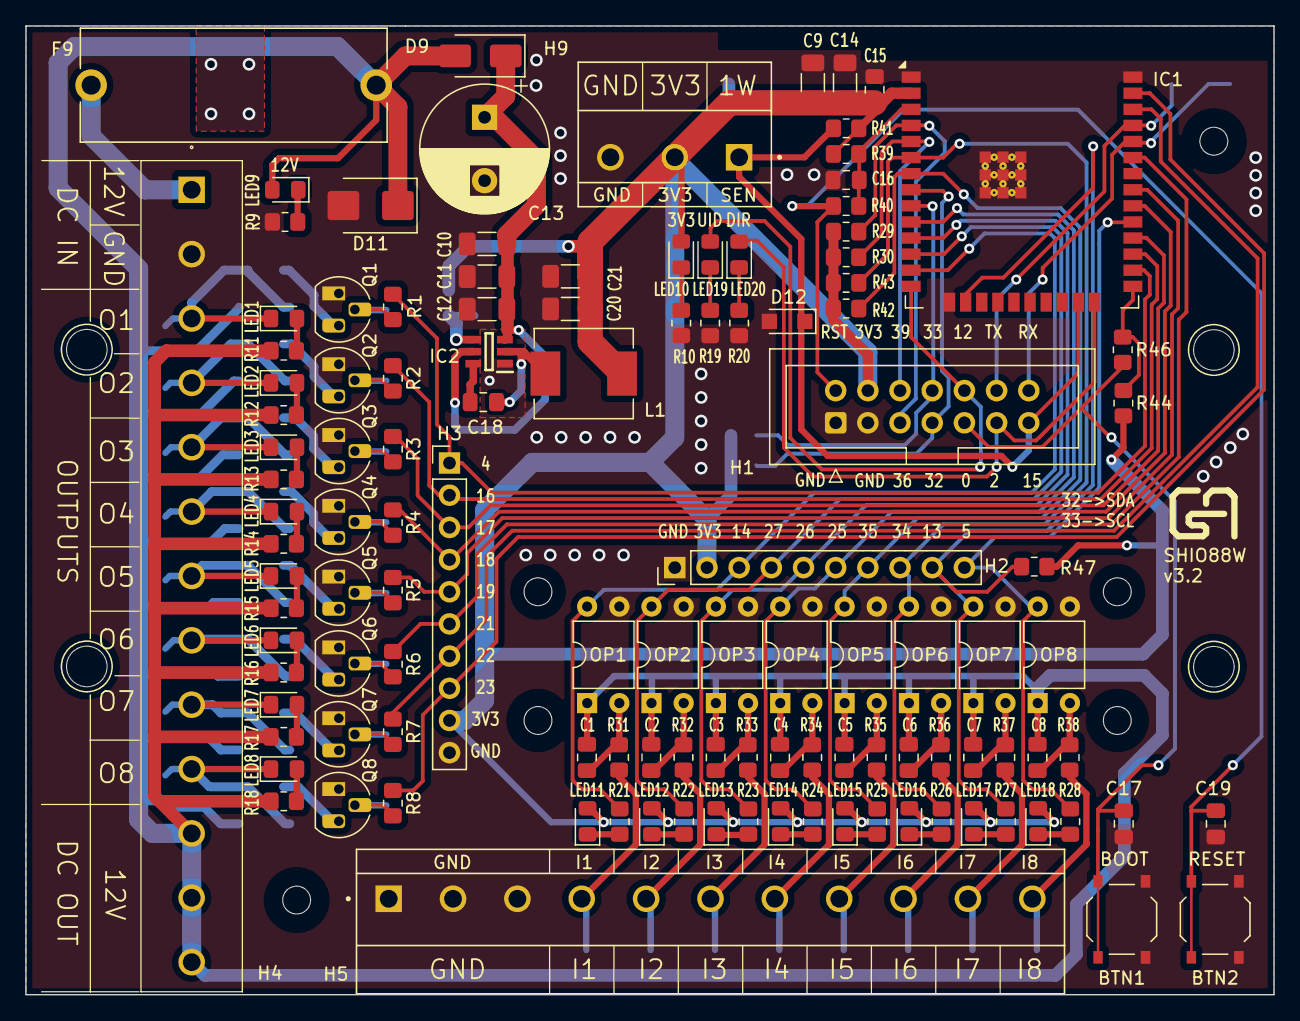
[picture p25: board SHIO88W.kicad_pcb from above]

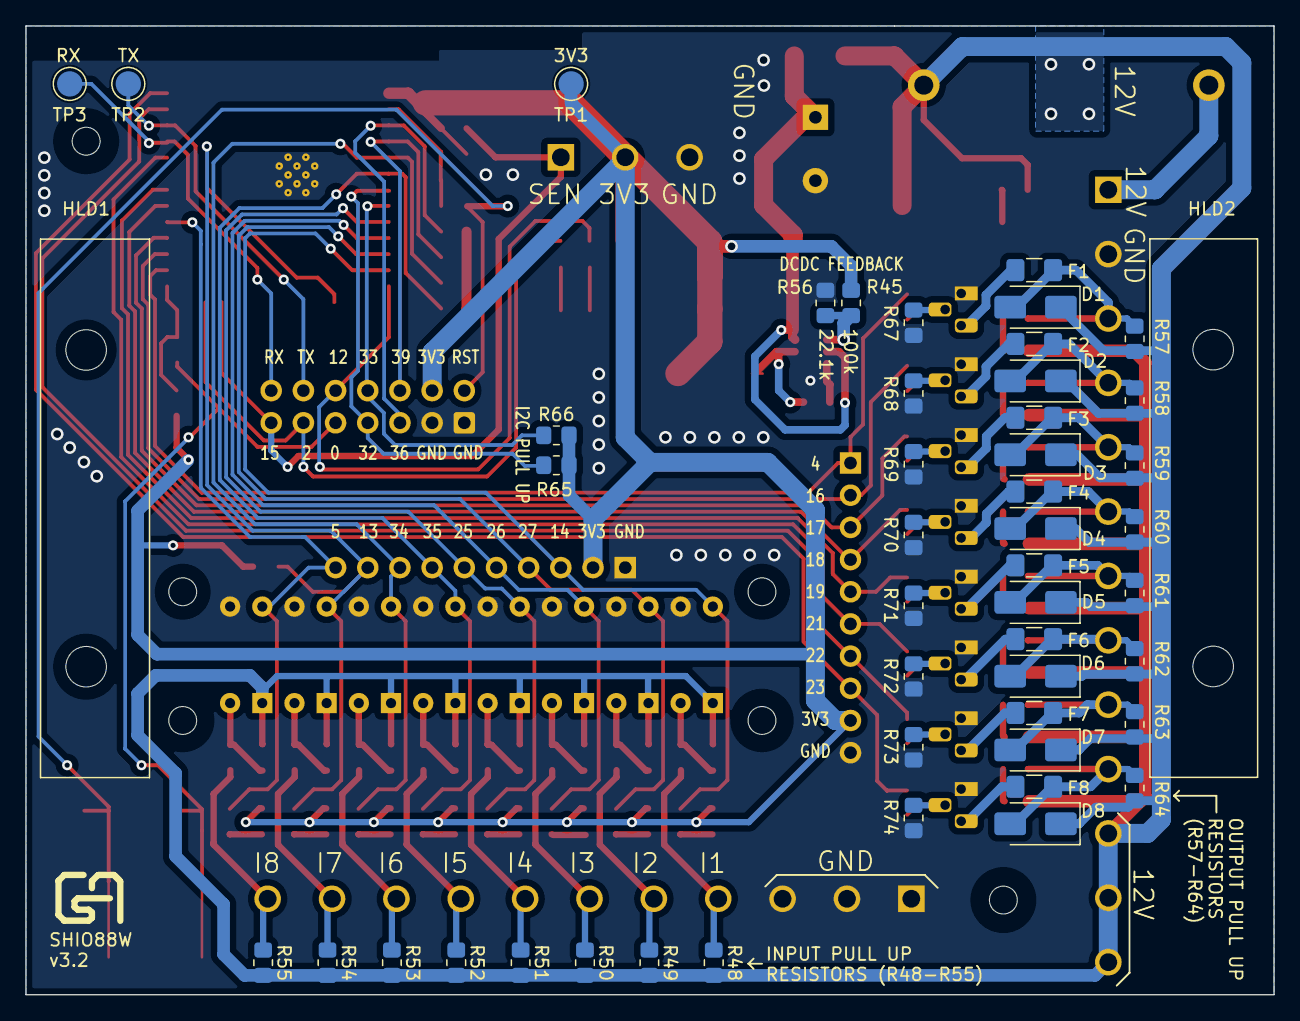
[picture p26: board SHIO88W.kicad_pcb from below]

Board: 2 copper layers, 98.5 x 76.5 mm, 167 parts (47 on the bottom side), 97 nets.

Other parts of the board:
HLD1, HLD2: DINRailAdapter_3xM3_PhoenixContact_1201578

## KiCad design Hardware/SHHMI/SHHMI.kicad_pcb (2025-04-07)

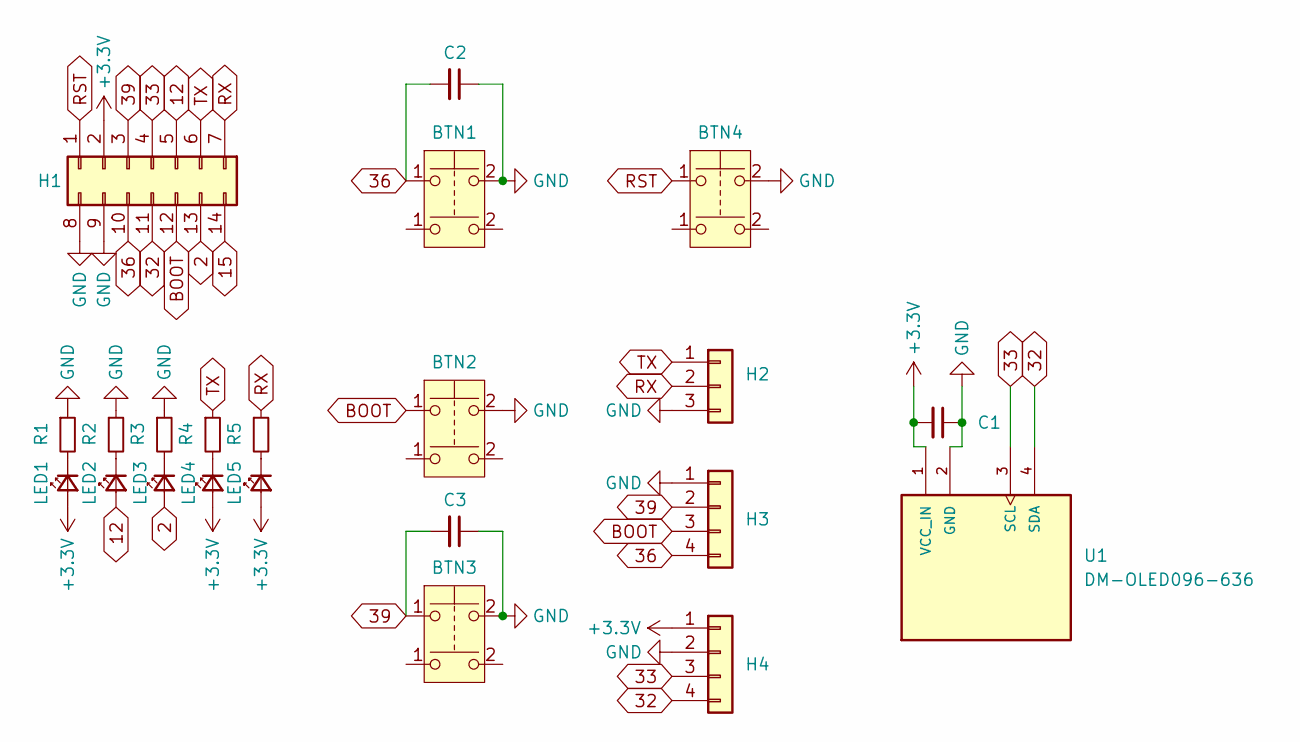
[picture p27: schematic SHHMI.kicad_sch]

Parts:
BTN1, BTN2, BTN3, BTN4: SW_Push_Dual; SW_SPST_PTS645_handsolder
C1, C2, C3: C_Small; C_0805_2012Metric_Pad1.18x1.45mm_HandSolder; LCSC C49678
H1: Conn_02x07_Top_Bottom; PinSocket_2x07_P2.54mm_Vertical
H2: Conn_01x03; PinHeader_1x03_P2.54mm_Vertical
H3, H4: Conn_01x04; PinHeader_1x04_P2.54mm_Vertical
LED1, LED5: LED_Small; LED_0805_2012Metric_Pad1.15x1.40mm_HandSolder; LCSC C2296
LED2: LED_Small; LED_0805_2012Metric_Pad1.15x1.40mm_HandSolder; LCSC C84256
LED3, LED4: LED_Small; LED_0805_2012Metric_Pad1.15x1.40mm_HandSolder; LCSC C2297
R1, R2, R3, R4, R5: R_Small; R_0805_2012Metric_Pad1.20x1.40mm_HandSolder; LCSC C17414
U1: DM-OLED096-636; display_oled_128x64_i2c; PARTREV 2018-09-10

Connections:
2: H1.13, LED3.2 (A)
12: H1.5, LED2.2 (A)
15: H1.14
32: H1.11, H4.4, U1.4 (SDA)
33: H1.4, H4.3, U1.3 (SCL)
36: BTN1.1, C2.2, H1.10, H3.4
39: BTN3.1, C3.2, H1.3, H3.2
+3.3V: C1.2, H1.2, H4.1, LED1.2 (A), LED4.2 (A), LED5.2 (A), U1.1 (VCC_IN)
BOOT: BTN2.1, H1.12, H3.3
GND: BTN1.2, BTN2.2, BTN3.2, BTN4.2, C1.1, C2.1, C3.1, H1.8, H1.9, H2.3, H3.1, H4.2, R1.1, R2.1, R3.1, U1.2 (GND)
unnamed: LED1.1 (K), R1.2
unnamed: LED2.1 (K), R2.2
unnamed: LED3.1 (K), R3.2
unnamed: LED4.1 (K), R4.2
unnamed: LED5.1 (K), R5.2
RST: BTN4.1, H1.1
RX: H1.7, H2.2, R5.1
TX: H1.6, H2.1, R4.1

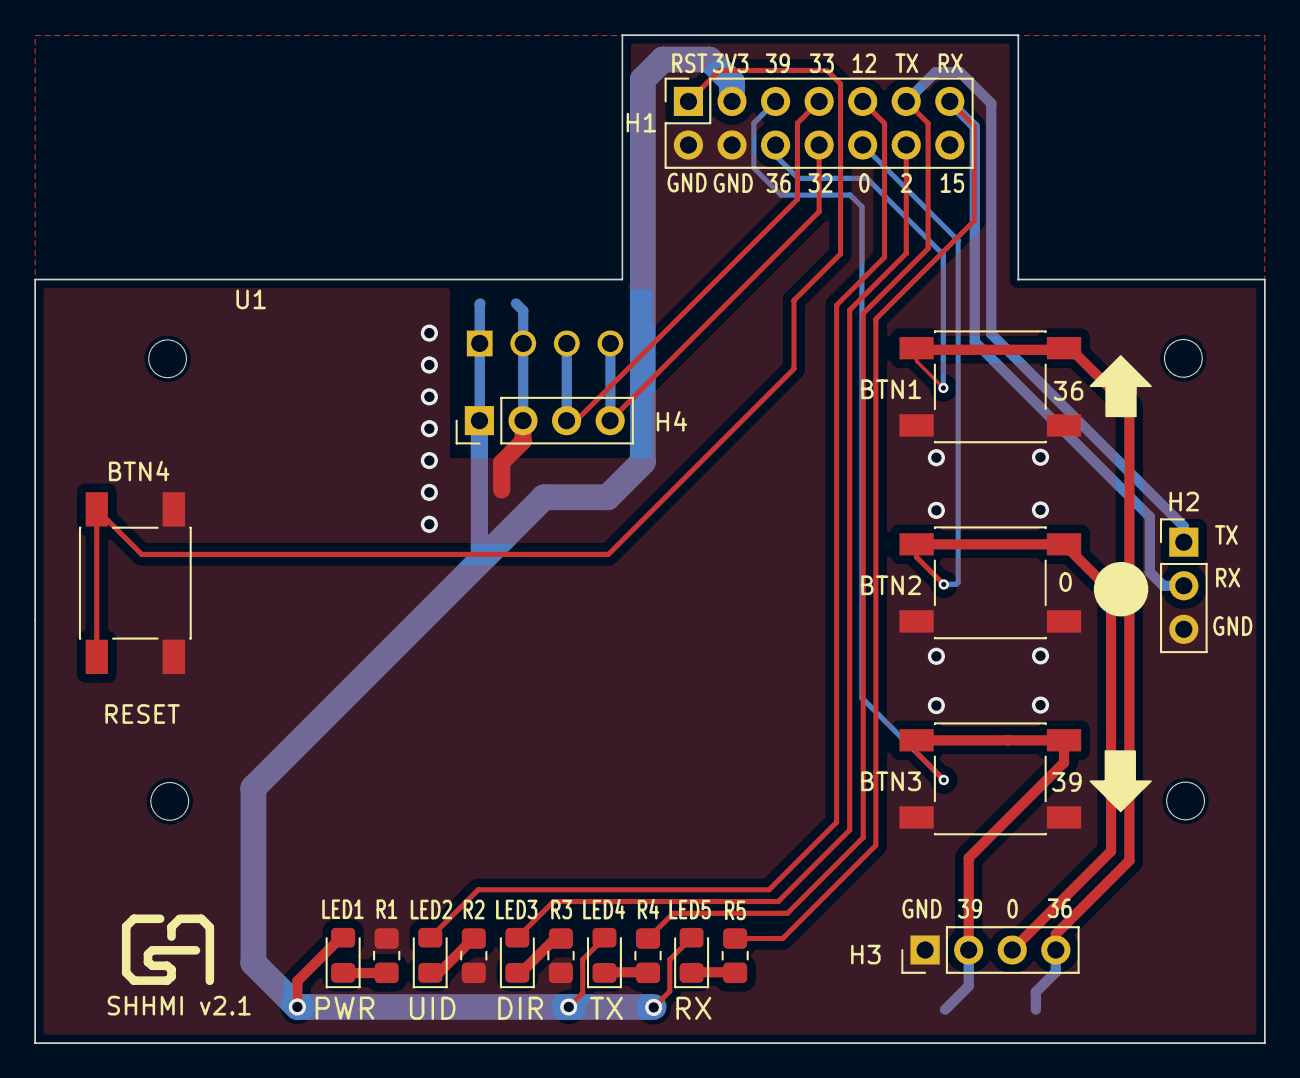
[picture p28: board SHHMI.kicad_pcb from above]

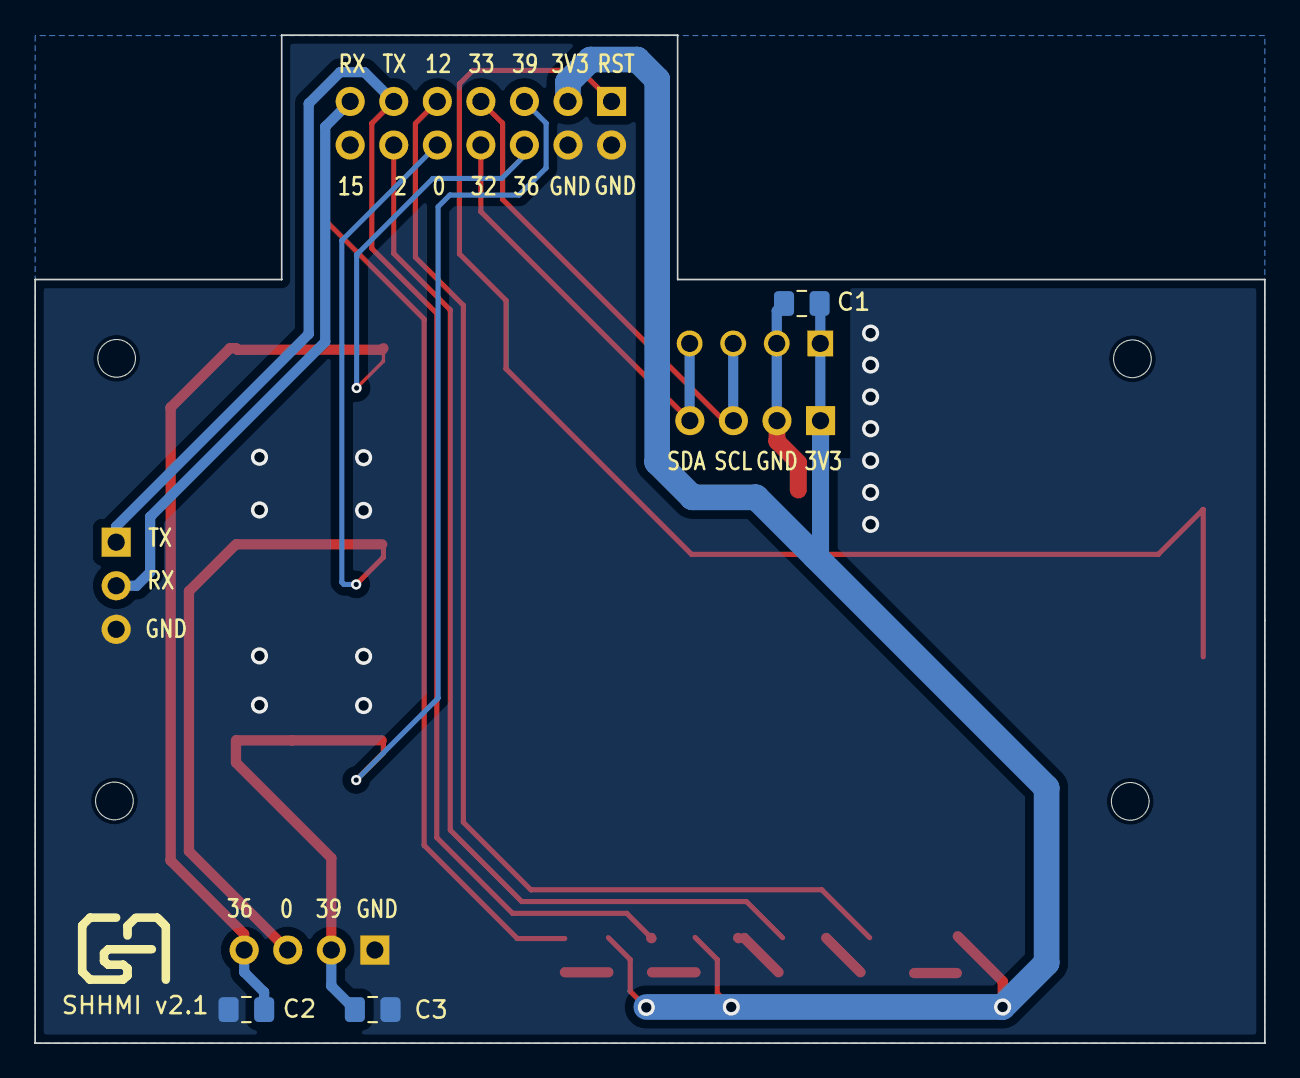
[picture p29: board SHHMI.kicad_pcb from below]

Board: 2 copper layers, 71.7 x 58.8 mm, 22 parts (3 on the bottom side), 17 nets.

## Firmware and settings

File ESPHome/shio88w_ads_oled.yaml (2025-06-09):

esphome:
  name: shio88w-ads-oled
  on_boot:
    - priority: 600
      then:
        - display.page.show: info
        - switch.turn_on: uid
        - delay: 500ms
        - switch.turn_off: uid
    - priority: 250
      then:
        - switch.turn_on: uid
        - delay: 500ms
        - switch.turn_off: uid

esp32:
  board: esp32dev
  framework:
    type: arduino

# Enable logging
logger:
  level: DEBUG
  baud_rate: 0

# Enable Home Assistant API
api:
  password: ""
  reboot_timeout: 0s

ota:
  - platform: esphome
    password: ""

wifi:
  ssid: "ssid"
  password: "password"
  # Enable fallback hotspot (captive portal) in case wifi connection fails
  ap:
    ssid: "SHIO88W Fallback Hotspot"
    password: "esphome1234"
  #use_address: 192.168.1.118

captive_portal:

web_server:
  version: 3
# Activates prometheus /metrics endpoint
prometheus:
  
globals:
   - id: last_press
     type: 'unsigned long'
     restore_value: no
     initial_value: '0'
   - id: menu_hide_delay
     type: 'int'
     restore_value: no
     initial_value: '30'

time:
  - platform: sntp
    on_time:
      # Every minutes
      - seconds: 0
        minutes: /1
        then:
          - lambda: |-
              int elapsed = (millis() - id(last_press)) / 1000;
              if(elapsed > id(menu_hide_delay)){
                id(my_menu).hide();
                id(clear).show();
              }

switch:
  - platform: gpio
    id: O1
    name: "O1"
    pin: 4
  - platform: gpio
    id: O2
    name: "O2"
    pin: 16
  - platform: gpio
    id: O3
    name: "O3"
    pin: 17
  - platform: gpio
    id: O4
    name: "O4"
    pin: 18
  - platform: gpio
    id: O5
    name: "O5"
    pin: 19
  - platform: gpio
    id: O6
    name: "O6"
    pin: 21
  - platform: gpio
    id: O7
    name: "O7"
    pin: 22
  - platform: gpio
    id: O8
    name: "O8"
    pin: 23
  - platform: gpio
    id: uid
    name: "UID"
    pin: 12

binary_sensor:
#inputs on terminal blocks
  - platform: gpio
    id: I1
    name: "I1"
    pin:
      number: 14
      inverted: true
      mode:
        input: true
        pullup: true
    on_press:
      then:
        - switch.turn_on: O1
    on_release:
      then:
        - switch.turn_off: O1
  - platform: gpio
    id: I2
    name: "I2"
    pin:
      number: 27
      inverted: true
      mode:
        input: true
        pullup: true
  - platform: gpio
    id: I3
    name: "I3"
    pin:
      number: 26
      inverted: true
      mode:
        input: true
        pullup: true
  - platform: gpio
    id: I4
    name: "I4"
    pin:
      number: 25
      inverted: true
      mode:
        input: true
        pullup: true
  - platform: gpio
    id: I5
    name: "I5"
    pin:
      number: 35
      inverted: true
      mode:
        input: true
  - platform: gpio
    id: I6
    name: "I6"
    pin:
      number: 34
      inverted: true
      mode:
        input: true
  - platform: gpio
    id: I7
    name: "I7"
    pin:
      number: 13
      inverted: true
      mode:
        input: true
        pullup: true
  - platform: gpio
    id: I8
    name: "I8"
    pin:
      number: 5
      inverted: true
      mode:
        input: true
        pullup: true
#buttons
  - platform: gpio
    name: "BTN F1"
    pin:
      number: 36
      inverted: true
      mode:
        input: true
    on_press:
          - display_menu.up: my_menu
          - lambda: |-
              id(last_press) = millis();
  - platform: gpio
    name: "BTN F2"
    pin:
      number: 39
      inverted: true
      mode:
        input: true
    on_press:
      - display_menu.down: my_menu
      - lambda: |-
          id(last_press) = millis();
  - platform: gpio
    name: "BTN BOOT"
    pin:
      number: 0
      inverted: true
      mode:
        input: true
    on_press:
    - if:
       condition:
          display_menu.is_active: my_menu
       then:
          - display_menu.enter: my_menu
       else:
          - display_menu.show:  my_menu
    - lambda: |-
        id(last_press) = millis();
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
